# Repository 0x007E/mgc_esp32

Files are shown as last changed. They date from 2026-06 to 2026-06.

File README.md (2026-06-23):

  

# `MGC_module` - ESP32

The `ESP32` (`mgc_module`) is an adaptable board for the [MeGARCard](https://github.com/0x007e/mgc). The board offers the possibility to control the `MeGARCard` with an [ESP32](#additional-information). The board itself is connected to the `MeGARCard` within the pcb-to-pcb connectors (no soldering necessary). With the onboard dip-switches the boot setup and the port expander `twi` address can be modified. The board itself operates with `3V3` deliverd from the `MeGARCard`.

> To mount the board on the `MeGARCard` disconnect the power source (`USB-C` connector) or any other used source from the MeGARCard!

| Experience  | Level |
|:---|:---:|
| Soldering | ?% |

# Downloads

| Type | File | Description |
|:---:|:---:|:---|
| Schematic | [pdf](https://github.com/0x007E/mgc_esp32/releases/latest/download/schematic.pdf) / [cadlab](https://cadlab.io/project/30425/main/files) | Schematic files |
| Board | [pdf](https://github.com/0x007E/mgc_esp32/releases/latest/download/pcb.pdf) / [cadlab](https://cadlab.io/project/30425/main/files) | Board file |
| Drill | [pdf](https://github.com/0x007E/mgc_esp32/releases/latest/download/drill.pdf) | Drill file |
| BoM | [xlsx](https://github.com/0x007E/mgc_esp32/releases/latest/download/bom.xlsx) / [html](https://github.com/0x007E/mgc_esp32/releases/latest/download/ibom.html) | Bill of Material as Excel/interactive HTML |
| PCB | [zip](https://github.com/0x007E/mgc_esp32/releases/latest/download/kicad.zip) / [tar](https://github.com/0x007E/mgc_esp32/releases/latest/download/kicad.tar.gz) | KiCAD/Gerber/BoM/Drill files |

# Hardware

The pcb is created with `KiCAD`. All files are built with `github actions` so that they are ready for a production environment.

## PCB

The circuit board is populated on both sides (Top, Bottom). The best way for soldering the `SMD` components is within a vapor phase soldering system and for the `THT` components with a standard soldering system.

### Top Layer

Top Layer

### Bottom Layer

Bottom Layer

# Additional Information

| Type | Link | Description |
|:---:|:---:|:---|
| ESP32  | [pdf](https://documentation.espressif.com/esp32-wroom-32e_esp32-wroom-32ue_datasheet_en.pdf) | ESP32-WROOM-32UE Datasheet |

---

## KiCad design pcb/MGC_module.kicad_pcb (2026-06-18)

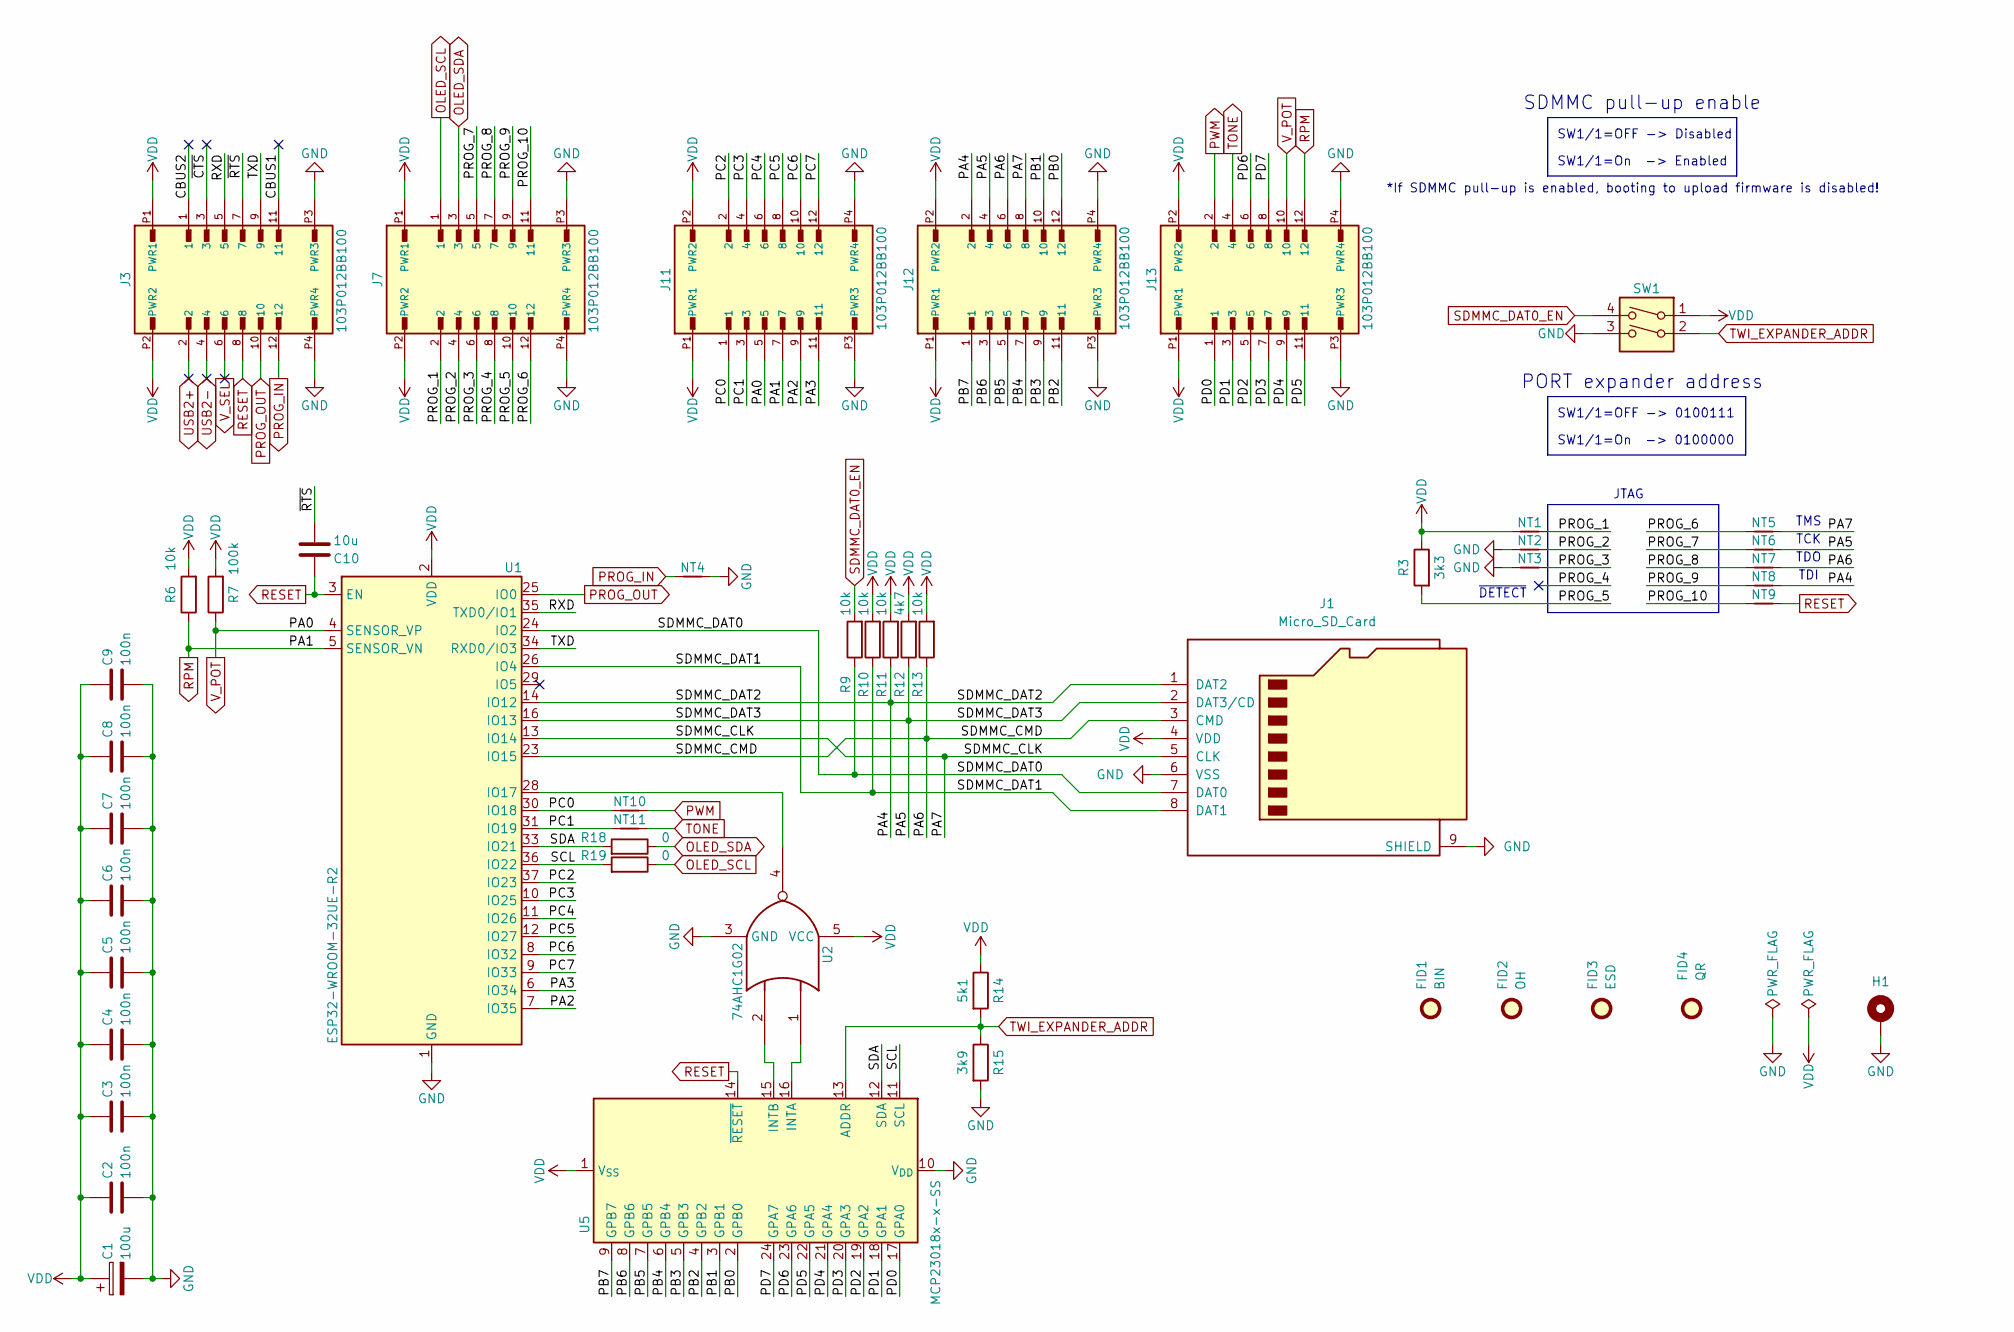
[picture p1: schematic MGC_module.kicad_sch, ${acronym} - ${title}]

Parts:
C1: 100u; CP_EIA-3528-21_Kemet-B; DigiKey 478-3877-1-ND
C2, C3, C4, C5, C6, C7, C8, C9: 100n; C_1206_3216Metric
C10: 10u; C_1206_3216Metric
FID1: BIN; WEEE-Logo_4.2x6mm_SilkScreen
FID2: OH; OSHW-Logo2_7.3x6mm_SilkScreen
FID3: ESD; ESD-Logo_6.6x6mm_SilkScreen
FID4: QR; QR_0x007e_very_small
H1: MountingHole_Pad; MountingHole_2.7mm_M2.5_DIN965_Pad
J1: Micro_SD_Card; microSD_HC_Molex_47219-2001; DigiKey WM6698CT-ND
J3, J7, J11, J12, J13: 103P012BB100; AMPHENOL_103P012BB100; DigiKey 609-103P012BB100CT-ND
NT1, NT2, NT3, NT4, NT5, NT6, NT7, NT8, NT9, NT10, NT11: NetTie_2; NetTie-2_SMD_Pad0.5mm
R3: 3k3; R_1206_3216Metric
R6, R9, R10, R11, R13: 10k; R_1206_3216Metric
R7: 100k; R_1206_3216Metric
R12: 4k7; R_1206_3216Metric
R14: 5k1; R_1206_3216Metric
R15: 3k9; R_1206_3216Metric
R18, R19: 0; R_1206_3216Metric
SW1: SW_DIP_x02; SW_DIP_SPSTx02_Slide_6.7x6.64mm_W6.73mm_P2.54mm_LowProfile_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
U1: ESP32-WROOM-32UE-R2; ESP32-WROOM-32U; DigiKey 1965-ESP32-WROOM-32UE-N4CT-ND, WM12219-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
U2: 74AHC1G02; SOT-23-5; DigiKey 296-8742-1-ND
U5: MCP23018x-x-SS; SSOP-24_5.3x8.2mm_P0.65mm; DigiKey 150-MCP23018T-E/SSCT-ND

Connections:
/CBUS1: J3.11
/CBUS2: J3.1
/PA2: J11.9, U1.7 (IO35)
/PA3: J11.11, U1.6 (IO34)
/PA4: J1.1 (DAT2), J12.2, NT8.2, R11.1, U1.14 (IO12)
/PA5: J1.2 (DAT3/CD), J12.4, NT6.2, R12.1, U1.16 (IO13)
/PA6: J1.3 (CMD), J12.6, NT7.2, R13.1, U1.23 (IO15)
/PA7: J1.5 (CLK), J12.8, NT5.2, U1.13 (IO14)
/PB0: J12.12, U5.2 (GPB0)
/PB1: J12.10, U5.3 (GPB1)
/PB2: J12.11, U5.4 (GPB2)
/PB3: J12.9, U5.5 (GPB3)
/PB4: J12.7, U5.6 (GPB4)
/PB5: J12.5, U5.7 (GPB5)
/PB6: J12.3, U5.8 (GPB6)
/PB7: J12.1, U5.9 (GPB7)
/PC0: J11.1, NT10.1, U1.30 (IO18)
/PC1: J11.3, NT11.1, U1.31 (IO19)
/PC2: J11.2, U1.37 (IO23)
/PC3: J11.4, U1.10 (IO25)
/PC4: J11.6, U1.11 (IO26)
/PC5: J11.8, U1.12 (IO27)
/PC6: J11.10, U1.8 (IO32)
/PC7: J11.12, U1.9 (IO33)
/PD0: J13.1, U5.17 (GPA0)
/PD1: J13.3, U5.18 (GPA1)
/PD2: J13.5, U5.19 (GPA2)
/PD3: J13.7, U5.20 (GPA3)
/PD4: J13.9, U5.21 (GPA4)
/PD5: J13.11, U5.22 (GPA5)
/PD6: J13.6, U5.23 (GPA6)
/PD7: J13.8, U5.24 (GPA7)
/PROG_1: J7.2, NT1.2
/PROG_2: J7.4, NT2.2
/PROG_3: J7.6, NT3.2
/PROG_4: J7.8
/PROG_5: J7.10, R3.2
/PROG_6: J7.12, NT5.1
/PROG_7: J7.5, NT6.1
/PROG_8: J7.7, NT7.1
/PROG_9: J7.9, NT8.1
/PROG_10: J7.11, NT9.1
/RXD: J3.5, U1.35 (TXD0/IO1)
/SCL: R19.2, U1.36 (IO22), U5.11 (SCL)
/SDA: R18.2, U1.33 (IO21), U5.12 (SDA)
/SDMMC_DAT0: J1.7 (DAT0), R9.1, U1.24 (IO2)
/SDMMC_DAT1: J1.8 (DAT1), R10.1, U1.26 (IO4)
/TXD: J3.9, U1.34 (RXD0/IO3)
/~CTS: J3.3
/~RTS: C10.2, J3.7
GND: C1.2, C2.2, C3.2, C4.2, C5.2, C6.2, C7.2, C8.2, C9.2, H1.1, J1.6 (VSS), J1.9 (SHIELD), J3.P3 (PWR3), J3.P4 (PWR4), J7.P3 (PWR3), J7.P4 (PWR4), J11.P3 (PWR3), J11.P4 (PWR4), J12.P3 (PWR3), J12.P4 (PWR4), J13.P3 (PWR3), J13.P4 (PWR4), NT2.1, NT3.1, NT4.2, R15.2, SW1.3, U1.1 (GND), U1.15 (GND), U1.38 (GND), U1.39 (GND), U2.3 (GND), U5.10 (V_{DD})
unnamed: U1.28 (IO17), U2.4
unnamed: U2.1, U5.16 (INTA)
unnamed: U2.2, U5.15 (INTB)
OLED_SCL: J7.1, R19.1
OLED_SDA: J7.3, R18.1
PROG_IN: J3.12, NT4.1
PROG_OUT: J3.10, U1.25 (IO0)
PWM: J13.2, NT10.2
RESET: C10.1, J3.8, NT9.2, U1.3 (EN), U5.14 (~RESET)
RPM: J11.7, J13.12, R6.1, U1.5 (SENSOR_VN)
SDMMC_DAT0_EN: R9.2, SW1.4
TONE: J13.4, NT11.2
TWI_EXPANDER_ADDR: R14.2, R15.1, SW1.2, U5.13 (ADDR)
USB2+: J3.2
USB2-: J3.4
VDD: C1.1, C2.1, C3.1, C4.1, C5.1, C6.1, C7.1, C8.1, C9.1, J1.4 (VDD), J3.P1 (PWR1), J3.P2 (PWR2), J7.P1 (PWR1), J7.P2 (PWR2), J11.P1 (PWR1), J11.P2 (PWR2), J12.P1 (PWR1), J12.P2 (PWR2), J13.P1 (PWR1), J13.P2 (PWR2), NT1.1, R3.1, R6.2, R7.2, R10.2, R11.2, R12.2, R13.2, R14.1, SW1.1, U1.2 (VDD), U2.5 (VCC), U5.1 (V_{SS})
V_POT: J11.5, J13.10, R7.1, U1.4 (SENSOR_VP)
V_SEL: J3.6

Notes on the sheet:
SW1/1=OFF -> Disabled
TMS
SW1/1=On -> Enabled
SW1/1=OFF -> 0100111
PORT expander address
*If SDMMC pull-up is enabled, booting to upload firmware is disabled!
SDMMC pull-up enable
~{DETECT}
SW1/1=On -> 0100000
JTAG
TCK
TDI
TDO

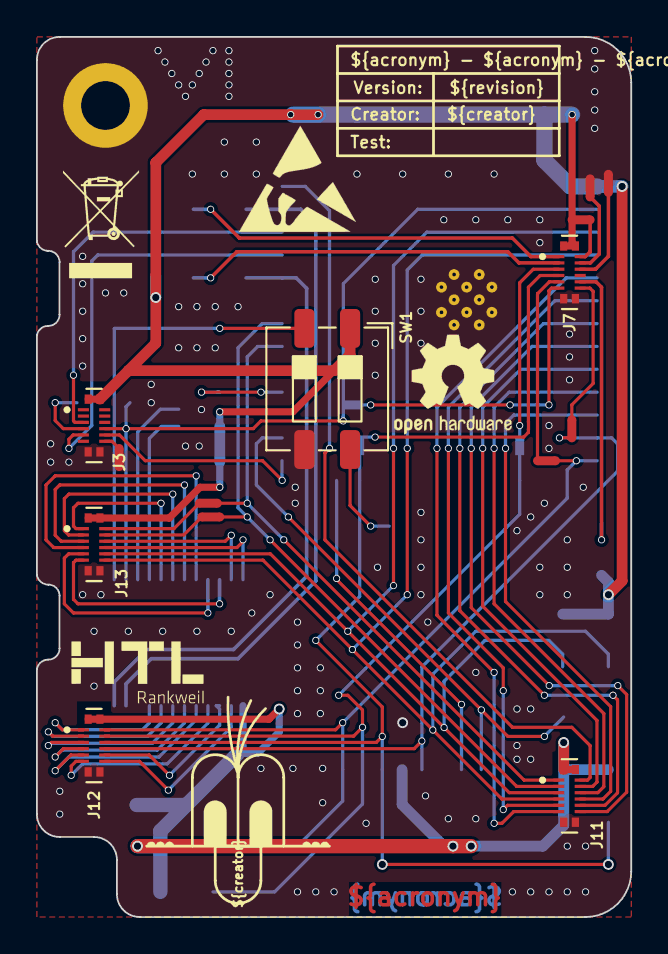
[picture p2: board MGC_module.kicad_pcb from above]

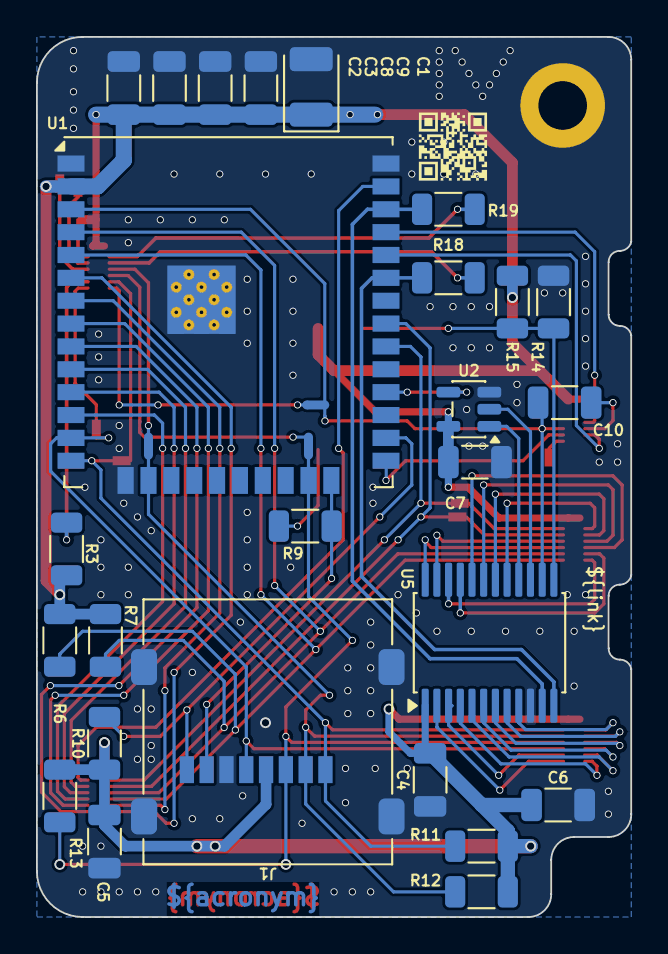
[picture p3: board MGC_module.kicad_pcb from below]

Board: 2 copper layers, 33.0 x 48.9 mm, 48 parts (30 on the bottom side), 62 nets.

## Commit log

2026-06-13 Add pcb layout
    [MGC_module.kicad_pcb, MGC_module.kicad_sch]
2026-06-13 Add missing vendor(id)
    [MGC_module.kicad_pcb, MGC_module.kicad_sch]
2026-06-18 Fix unconnected labels
    [MGC_module.kicad_pcb, MGC_module.kicad_sch]
2026-06-23 Add missing values in bom

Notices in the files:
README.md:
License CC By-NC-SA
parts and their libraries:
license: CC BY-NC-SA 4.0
